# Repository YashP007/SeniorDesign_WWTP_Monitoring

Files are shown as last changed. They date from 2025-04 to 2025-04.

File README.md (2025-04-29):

# Advancing Wastewater Monitoring through Engineered Biological Sensors

**Yash Patel, Kara Walp**  
Department of Biomedical Engineering, Senior Design, Group 4 (2024–2025)  
Advisors: Rabia Tuğçe Yazicigil Kirby (BME, ECE), Miguel Jimenez (BME, MSE)

---

## Abstract
Effective industrial wastewater monitoring is critical for regulatory compliance and process optimization. However, traditional analytical techniques such as high-performance liquid chromatography (HPLC) are costly, require centralized facilities, and introduce significant latency between sampling and actionable results. Advances in synthetic biology have enabled the engineering of microbial whole-cell biosensors capable of detecting environmental contaminants with high specificity and rapid response times. Yet, practical deployment is limited by microbial instability in harsh environments and the lack of compact, low-power systems for low-signal optical outputs.

This work presents a deployable biosensing platform integrating a microbe housing and a low-power optical detection system designed for in situ wastewater monitoring. A membrane-based chamber enhances microbial viability by modulating nutrient and oxygen diffusion while preventing environmental microbial egress. Optical detection of luminescence was achieved using an analog front end with noise shaping and oversampling, enabling quantification of multiple biosensor outputs.

Experimental validation demonstrated improved microbial stability with Escherichia coli, extending viability beyond typical single-use constraints. The integrated system successfully captured optical responses from biosensors at environmentally relevant analyte concentrations. These findings highlight a promising pathway toward continuous, real-time wastewater monitoring using whole-cell biosensors. Future work must address challenges related to thermal robustness and variable contaminant backgrounds to achieve broader commercial deployment.

Contents:
Aim 1 - Creating a Microbe Housing for Deployment in Wastewater Treatment Plants
Aim 2 - Creating a Deployable Optical Detection Circuit

1. STL Files for Microbe Housing
2. Image Procesing Code for evaluating the microbe housing using the plate reader
3. KiCAD Files for Final Optical Sensing Circuit
4. Optical Sensing Circuit ESP32-C3 Microcontroller Program

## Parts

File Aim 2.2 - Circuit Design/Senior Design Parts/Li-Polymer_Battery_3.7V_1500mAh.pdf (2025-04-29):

# Li-Polymer Battery 3.7V 1500mAh (https://www.mikroe.com/li-polymer-battery-37v-1500mah)

PID: MIKROE-4473

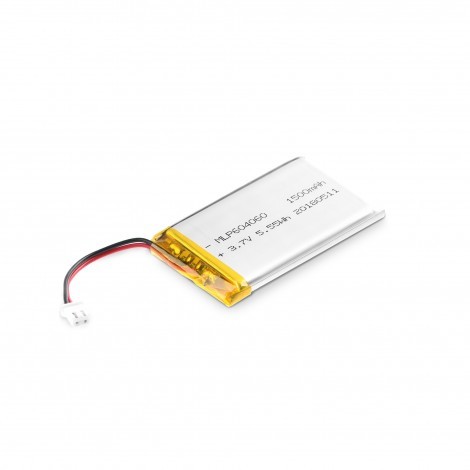
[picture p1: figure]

If you need a battery power supply, we have a great and compact solution. This rechargeable 1500mAh 3.7V battery can deliver even more.

### Downloads

MLP604060 datasheet (https://download.mikroe.com/documents/datasheets/MLP604060%201500mAh%203.7V.pdf)

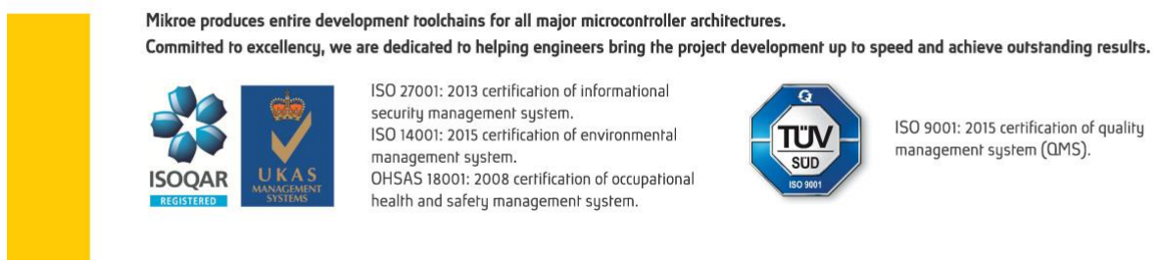
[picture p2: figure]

Powered by TCPDF (www.tcpdf.org)

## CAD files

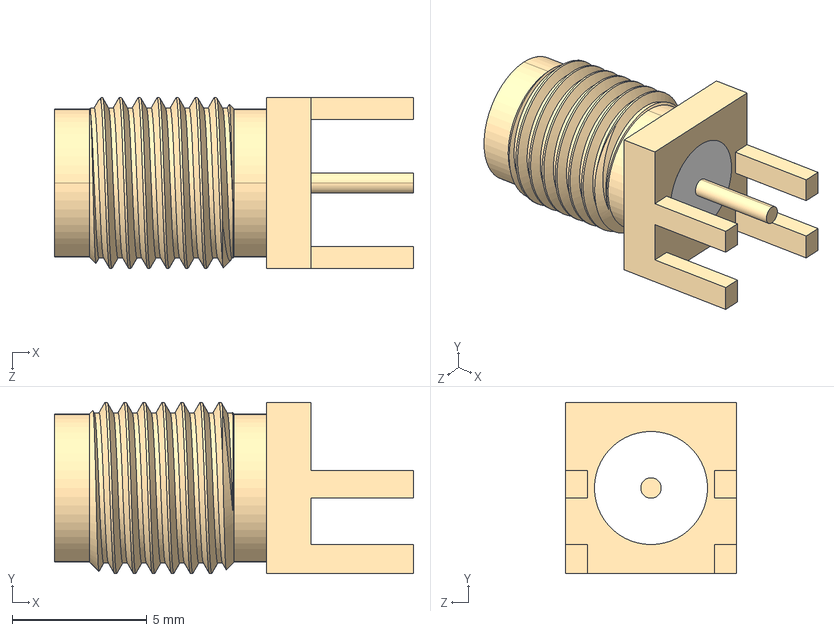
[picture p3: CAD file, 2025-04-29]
Aim 2.2 - Circuit Design/Senior Design Parts/CON_SMA_EDGE_S/CON-SMA-EDGE-S.step
13.3 x 6.35 x 6.35 mm

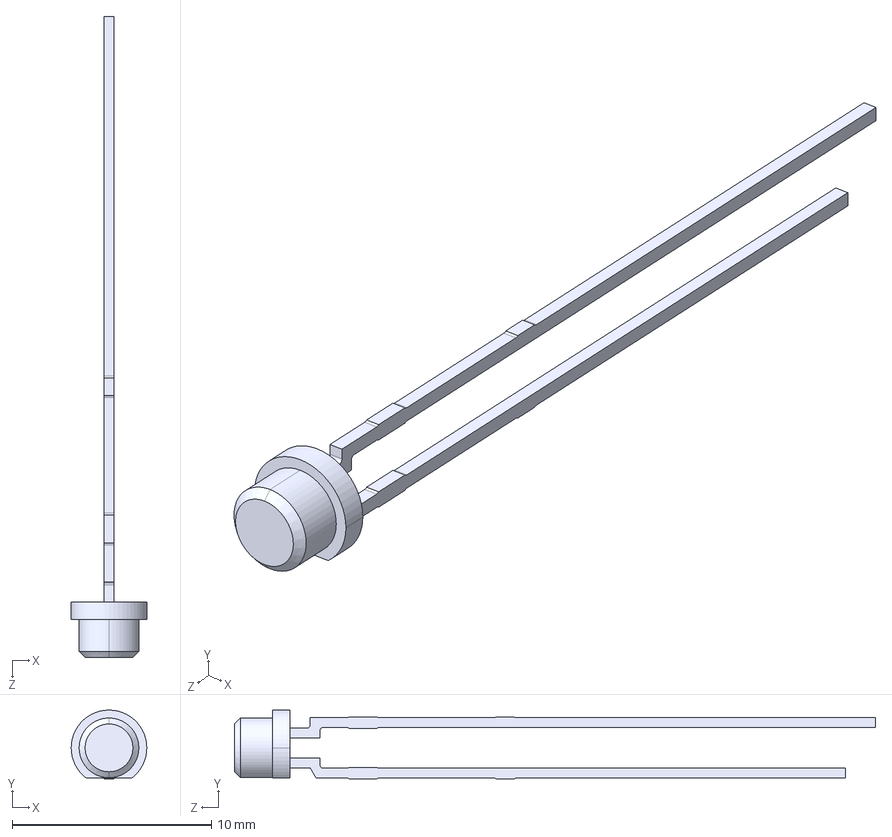
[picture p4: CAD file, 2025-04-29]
Aim 2.2 - Circuit Design/Senior Design Parts/LIB_SFH_3310/SFH_3310/3D/SFH_3310.stp
3.80 x 3.46 x 32.2 mm

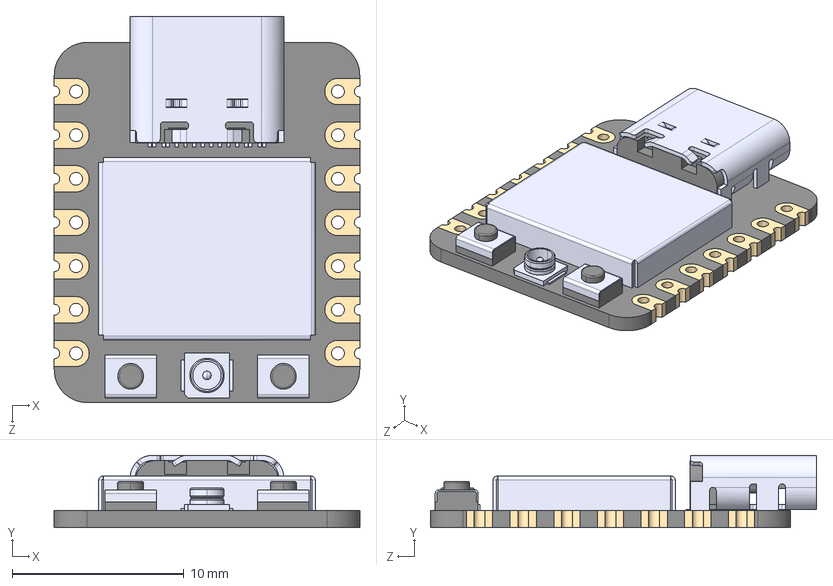
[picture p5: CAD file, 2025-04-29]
Aim 2.2 - Circuit Design/Senior Design Parts/ESP32_113991054/113991054.step
17.8 x 4.21 x 22.5 mm

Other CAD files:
Aim 2.2 - Circuit Design/Senior Design Parts/LIB_SFH_3310/SFH_3310/Allegro/sfh3310.psm
Aim 2.2 - Circuit Design/Senior Design Parts/LIB_SFH_3310/SFH_3310/DEHDL/sfh_3310/chips/chips.prt

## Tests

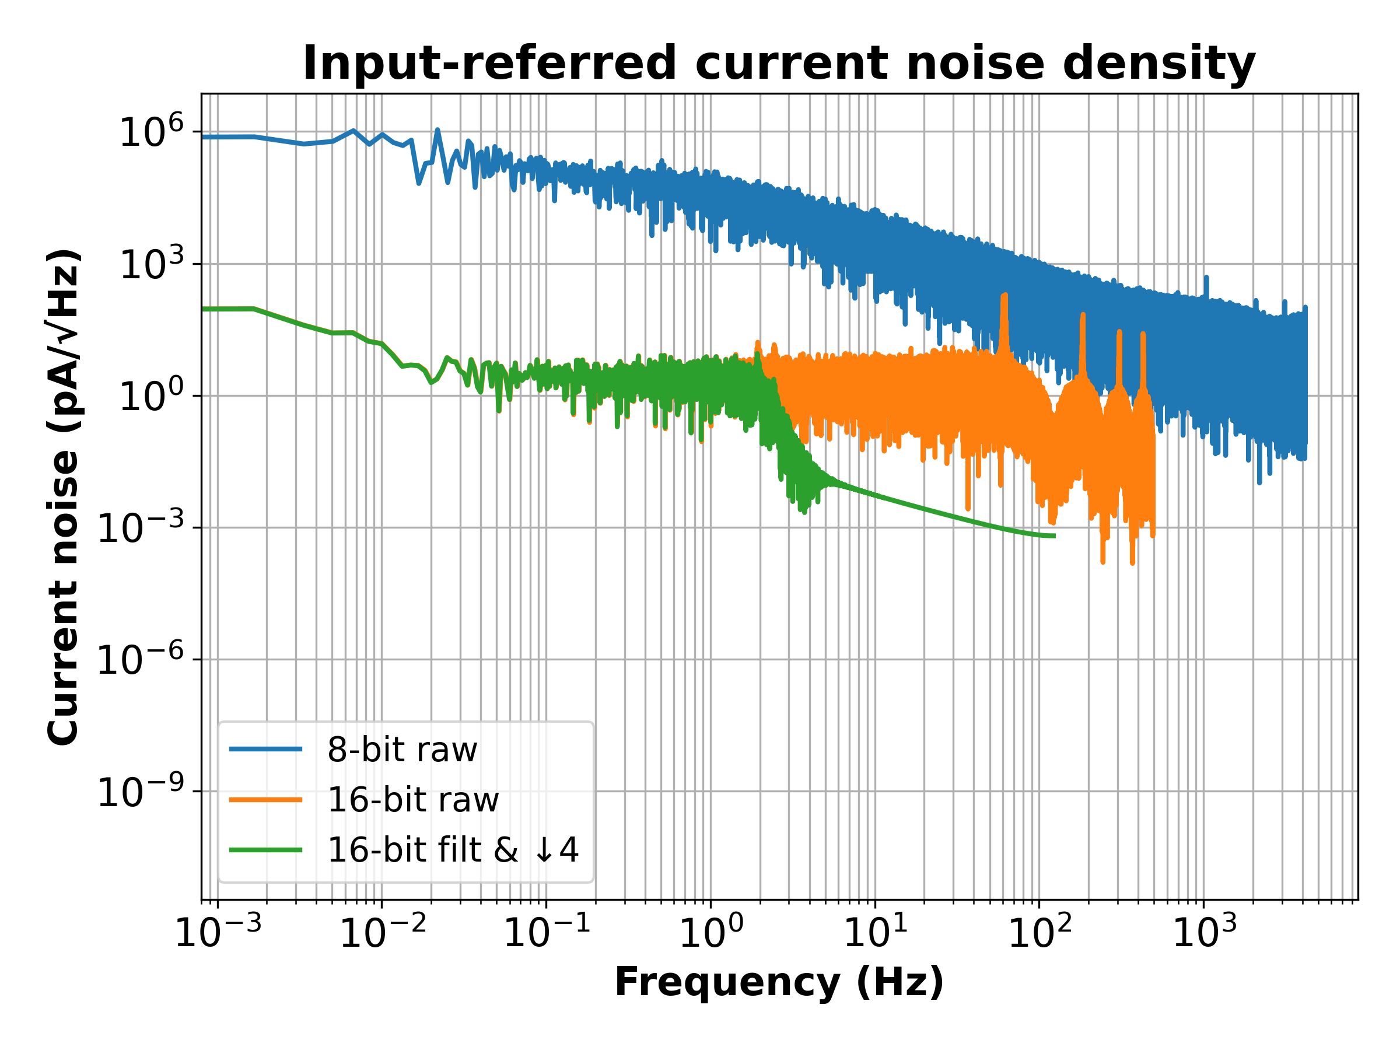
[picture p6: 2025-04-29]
Aim 2.5 - Electrical PCB Testing/Python Scripts/input_referred_current_noise.png

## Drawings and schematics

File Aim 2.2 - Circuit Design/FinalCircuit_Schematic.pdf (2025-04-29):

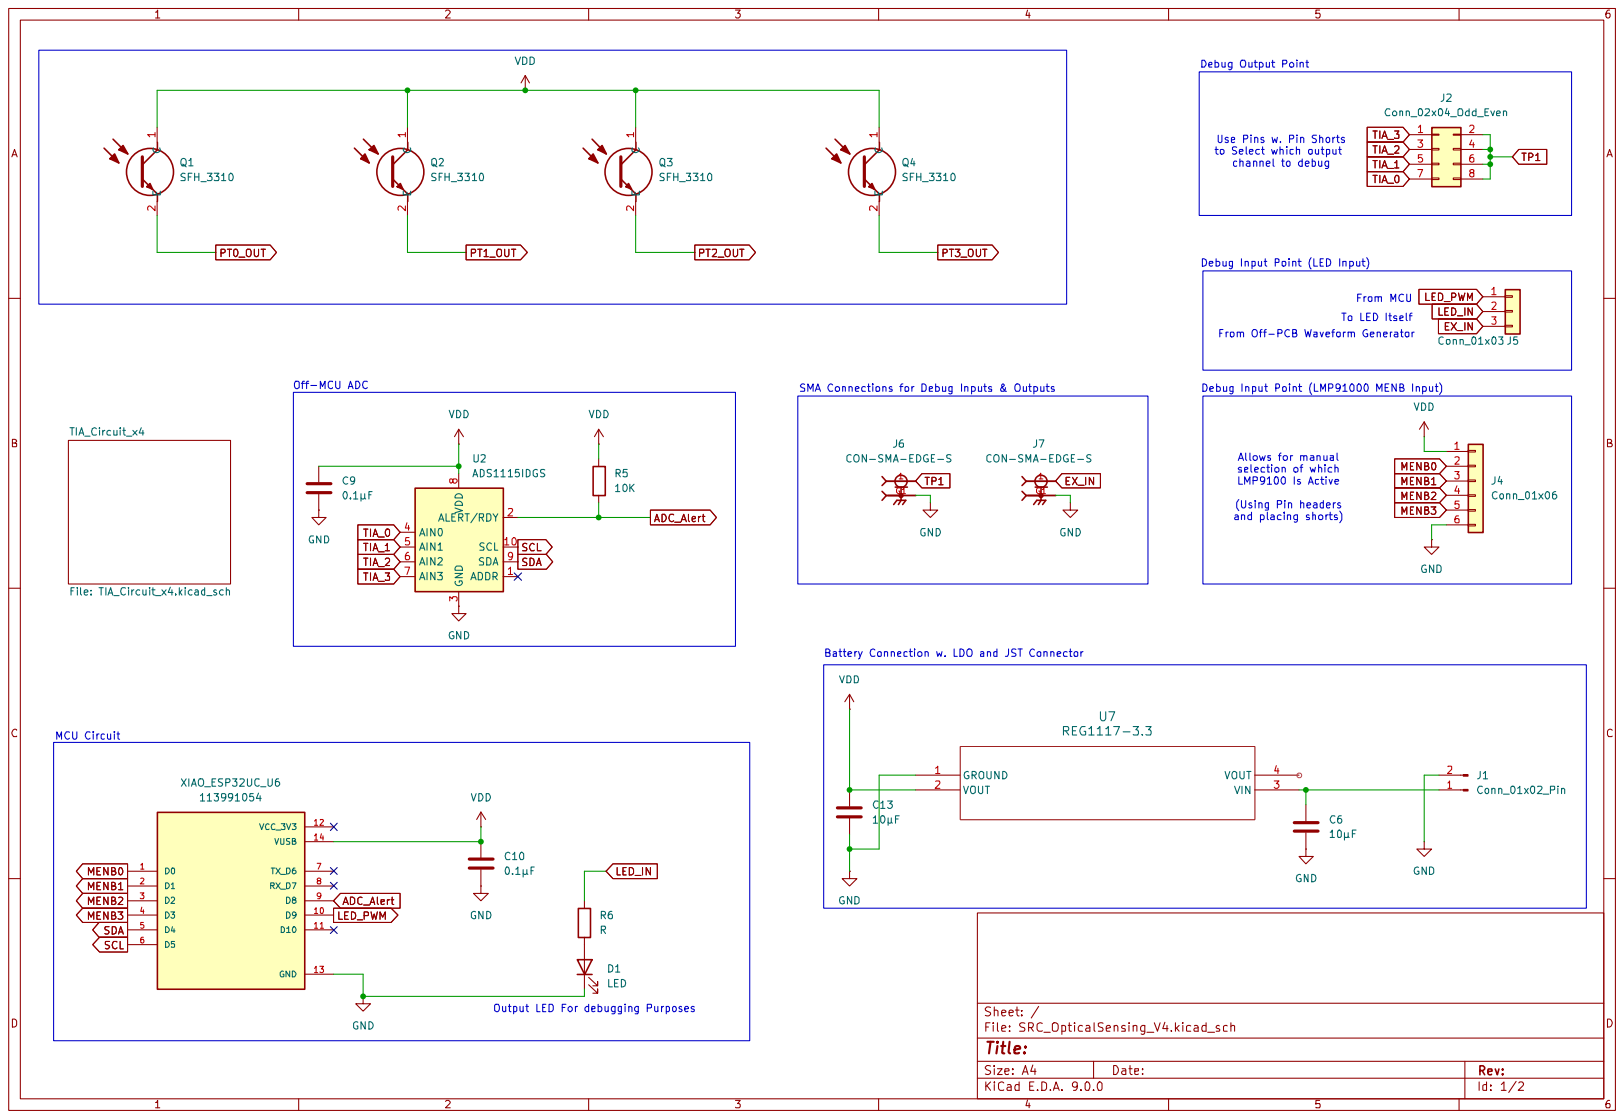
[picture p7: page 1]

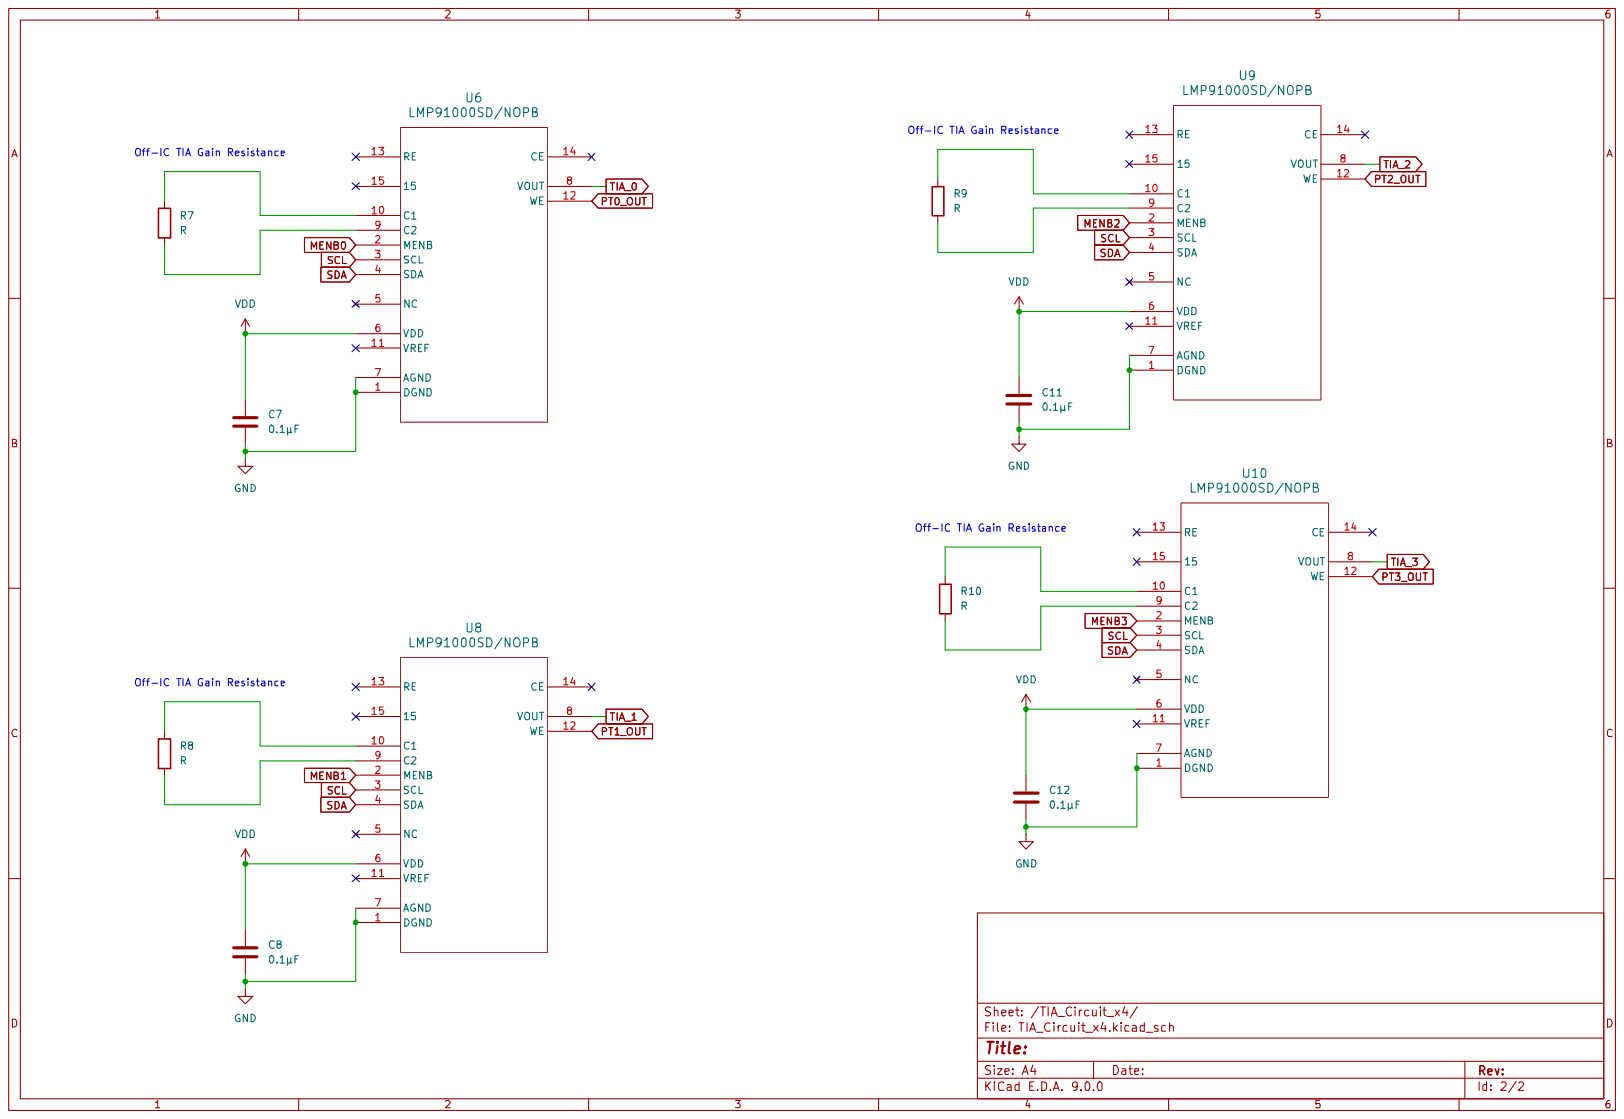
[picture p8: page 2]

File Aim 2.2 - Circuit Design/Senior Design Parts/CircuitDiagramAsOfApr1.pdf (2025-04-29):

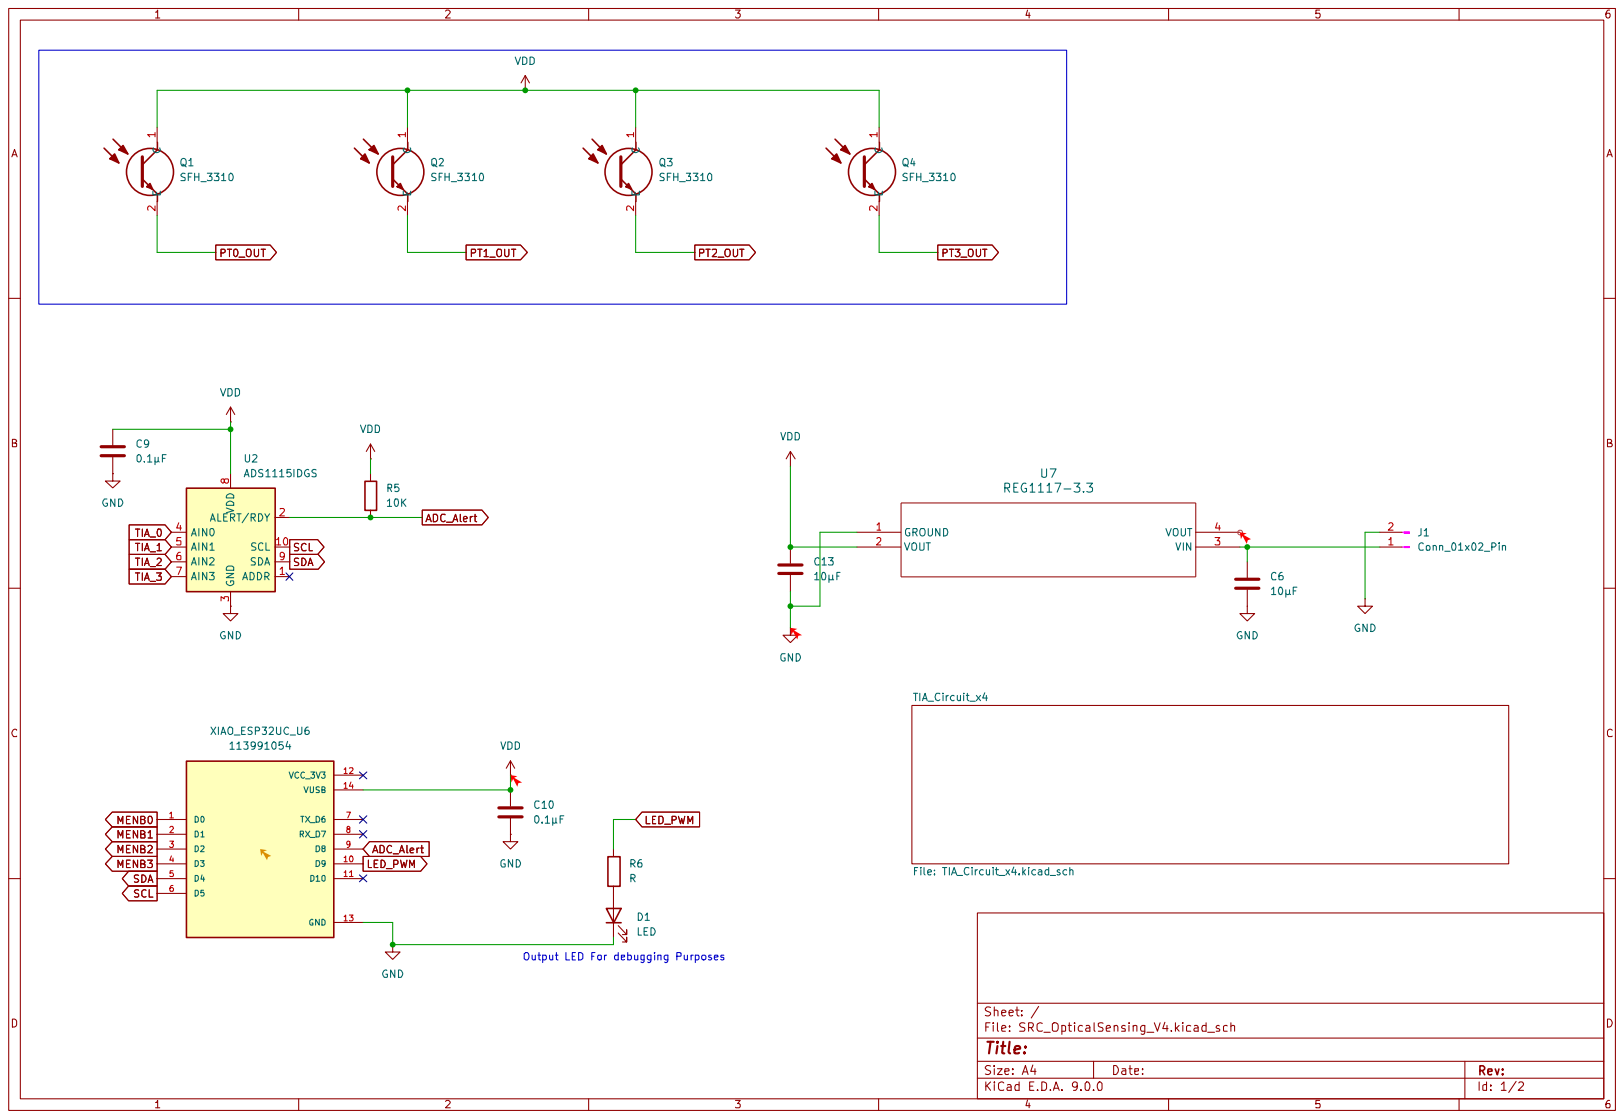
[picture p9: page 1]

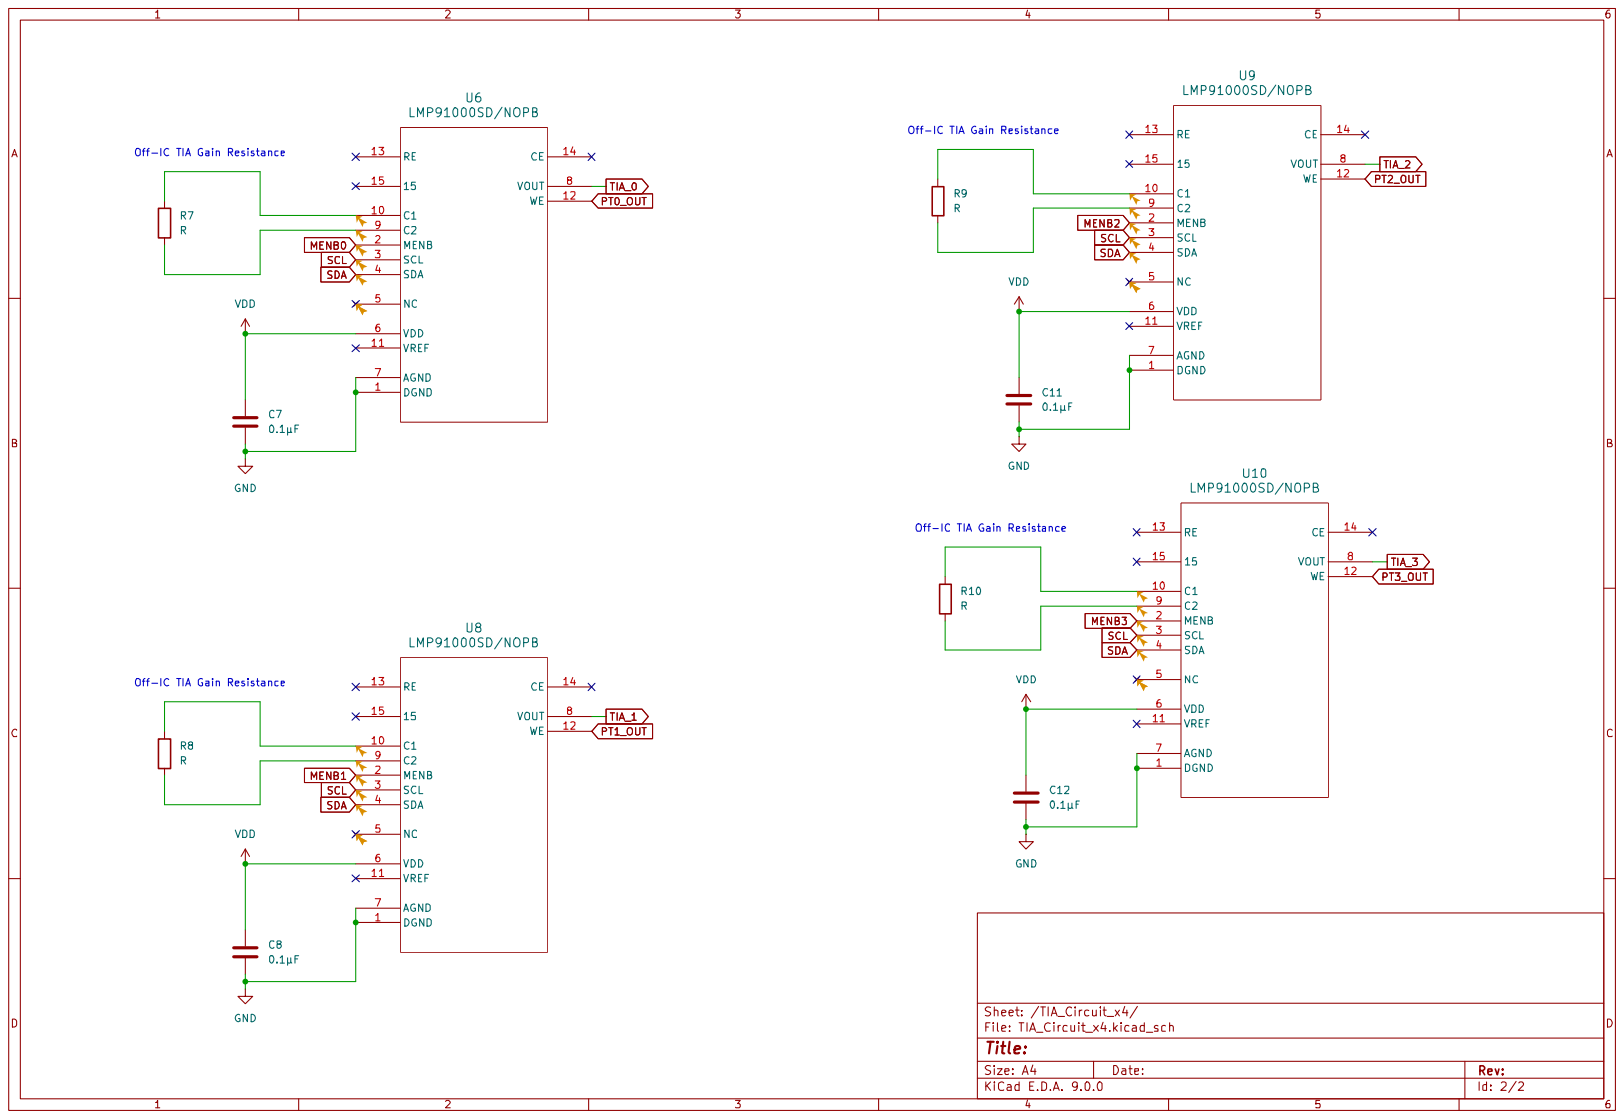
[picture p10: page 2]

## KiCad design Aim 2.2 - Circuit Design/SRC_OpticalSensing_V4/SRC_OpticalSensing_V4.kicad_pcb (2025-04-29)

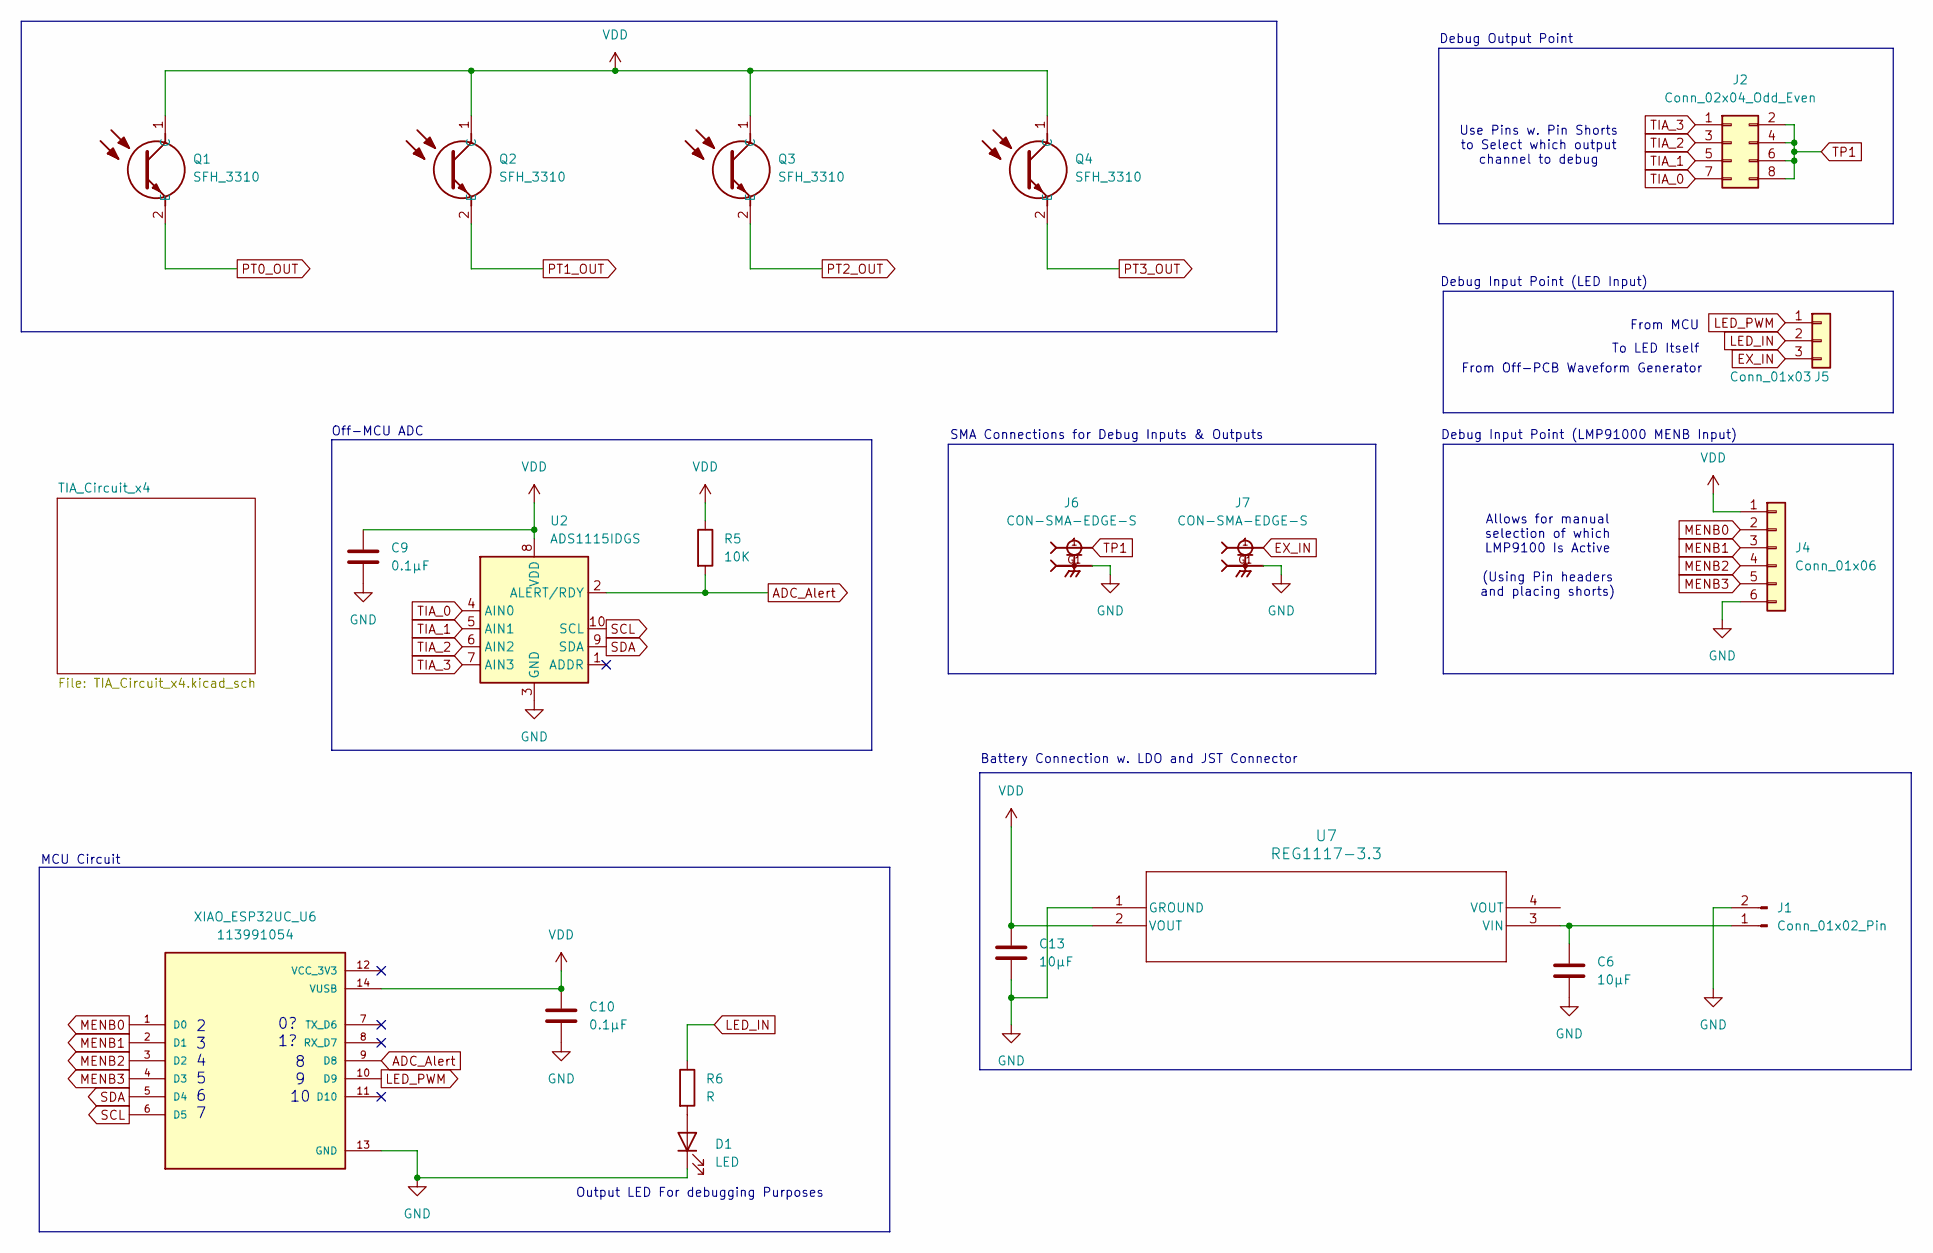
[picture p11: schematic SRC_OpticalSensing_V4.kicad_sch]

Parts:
C6, C13: 10µF; C_0805_2012Metric_Pad1.18x1.45mm_HandSolder
C9, C10: 0.1µF; C_0805_2012Metric_Pad1.18x1.45mm_HandSolder
D1: LED; LED_D5.0mm
J1: Conn_01x02_Pin; JWT_A3963_1x02_P3.96mm_Vertical
J2: Conn_02x04_Odd_Even; PinHeader_2x04_P2.54mm_Vertical
J4: Conn_01x06; PinHeader_1x06_P2.54mm_Vertical
J5: Conn_01x03; PinHeader_1x03_P2.54mm_Vertical
J6, J7: CON-SMA-EDGE-S; RFSOLUTIONS_CON-SMA-EDGE-S; PARTREV 1
Q1, Q2, Q3, Q4: SFH_3310; SFH3310; Mouser Part Number 720-SFH3310
R5: 10K; R_0805_2012Metric_Pad1.20x1.40mm_HandSolder
R6: R; R_0805_2012Metric_Pad1.20x1.40mm_HandSolder
U2: ADS1115IDGS; TSSOP-10_3x3mm_P0.5mm
U7: REG1117-3.3; DCY4
XIAO_ESP32UC_U6: 113991054; MODULE_113991054; PARTREV 23/05/2022

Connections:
ADC_Alert: R5.2, U2.2 (ALERT/RDY), XIAO_ESP32UC_U6.9 (D8)
EX_IN: J5.3, J7.1
GND: C6.2, C9.2, C10.2, C13.2, D1.1 (K), J1.2, J4.6, J6.G1, J7.G1, U2.3 (GND), U7.1 (GROUND), XIAO_ESP32UC_U6.13 (GND); also elsewhere on the board
LED_IN: J5.2, R6.1
LED_PWM: J5.1, XIAO_ESP32UC_U6.10 (D9)
MENB0: J4.2, XIAO_ESP32UC_U6.1 (D0); also elsewhere on the board
MENB1: J4.3, XIAO_ESP32UC_U6.2 (D1); also elsewhere on the board
MENB2: J4.4, XIAO_ESP32UC_U6.3 (D2); also elsewhere on the board
MENB3: J4.5, XIAO_ESP32UC_U6.4 (D3); also elsewhere on the board
unnamed: D1.2 (A), R6.2
unnamed: C6.1, J1.1, U7.3 (VIN)
PT0_OUT: Q1.2 (E); also elsewhere on the board
PT1_OUT: Q2.2 (E); also elsewhere on the board
PT2_OUT: Q3.2 (E); also elsewhere on the board
PT3_OUT: Q4.2 (E); also elsewhere on the board
SCL: U2.10 (SCL), XIAO_ESP32UC_U6.6 (D5); also elsewhere on the board
SDA: U2.9 (SDA), XIAO_ESP32UC_U6.5 (D4); also elsewhere on the board
TIA_0: J2.7, U2.4 (AIN0); also elsewhere on the board
TIA_1: J2.5, U2.5 (AIN1); also elsewhere on the board
TIA_2: J2.3, U2.6 (AIN2); also elsewhere on the board
TIA_3: J2.1, U2.7 (AIN3); also elsewhere on the board
TP1: J2.2, J2.4, J2.6, J2.8, J6.1
VDD: C9.1, C10.1, C13.1, J4.1, Q1.1 (C), Q2.1 (C), Q3.1 (C), Q4.1 (C), R5.1, U2.8 (VDD), U7.2 (VOUT), XIAO_ESP32UC_U6.14 (VUSB); also elsewhere on the board

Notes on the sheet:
Battery Connection w. LDO and JST Connector
6 7
Off-MCU ADC
From MCU
Use Pins w. Pin Shorts to Select which output channel to debug
Debug Input Point (LMP91000 MENB Input)
Allows for manual selection of which LMP9100 Is Active (Using Pin headers and placing shorts)
MCU Circuit
2 3 4 5
Debug Output Point
8 9 10
To LED Itself
SMA Connections for Debug Inputs & Outputs
0? 1?
Debug Input Point (LED Input)
From Off-PCB Waveform Generator
Output LED For debugging Purposes

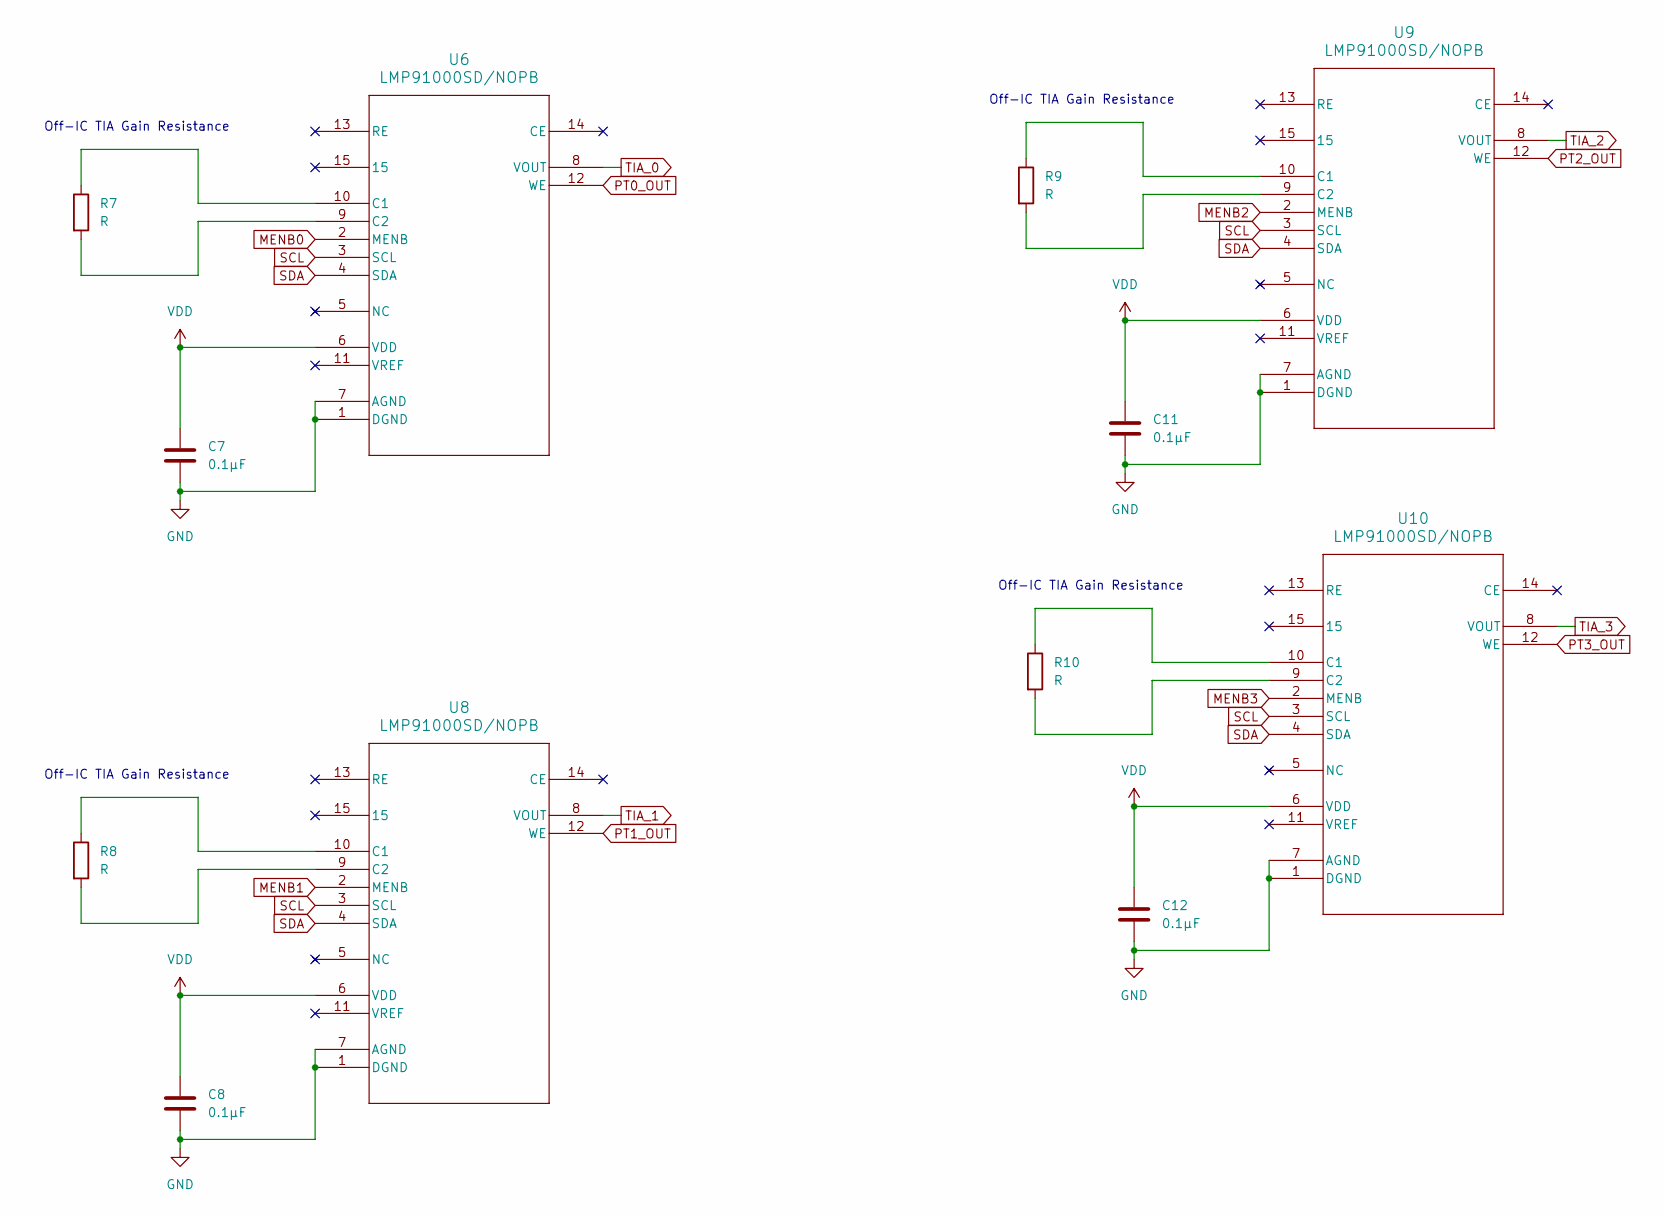
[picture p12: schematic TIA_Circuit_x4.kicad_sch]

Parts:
C7, C8, C11, C12: 0.1µF; C_0805_2012Metric_Pad1.18x1.45mm_HandSolder
R7, R8, R9, R10: R; R_0805_2012Metric_Pad1.20x1.40mm_HandSolder
U6, U8, U9, U10: LMP91000SD/NOPB; SDA14B

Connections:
GND: C7.2, C8.2, C11.2, C12.2, U6.1 (DGND), U6.7 (AGND), U8.1 (DGND), U8.7 (AGND), U9.1 (DGND), U9.7 (AGND), U10.1 (DGND), U10.7 (AGND); also elsewhere on the board
MENB0: U6.2 (MENB); also elsewhere on the board
MENB1: U8.2 (MENB); also elsewhere on the board
MENB2: U9.2 (MENB); also elsewhere on the board
MENB3: U10.2 (MENB); also elsewhere on the board
unnamed: R7.1, U6.10 (C1)
unnamed: R7.2, U6.9 (C2)
unnamed: R8.1, U8.10 (C1)
unnamed: R8.2, U8.9 (C2)
unnamed: R9.1, U9.10 (C1)
unnamed: R9.2, U9.9 (C2)
unnamed: R10.1, U10.10 (C1)
unnamed: R10.2, U10.9 (C2)
PT0_OUT: U6.12 (WE); also elsewhere on the board
PT1_OUT: U8.12 (WE); also elsewhere on the board
PT2_OUT: U9.12 (WE); also elsewhere on the board
PT3_OUT: U10.12 (WE); also elsewhere on the board
SCL: U6.3 (SCL), U8.3 (SCL), U9.3 (SCL), U10.3 (SCL); also elsewhere on the board
SDA: U6.4 (SDA), U8.4 (SDA), U9.4 (SDA), U10.4 (SDA); also elsewhere on the board
TIA_0: U6.8 (VOUT); also elsewhere on the board
TIA_1: U8.8 (VOUT); also elsewhere on the board
TIA_2: U9.8 (VOUT); also elsewhere on the board
TIA_3: U10.8 (VOUT); also elsewhere on the board
VDD: C7.1, C8.1, C11.1, C12.1, U6.6 (VDD), U8.6 (VDD), U9.6 (VDD), U10.6 (VDD); also elsewhere on the board

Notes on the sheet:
Off-IC TIA Gain Resistance

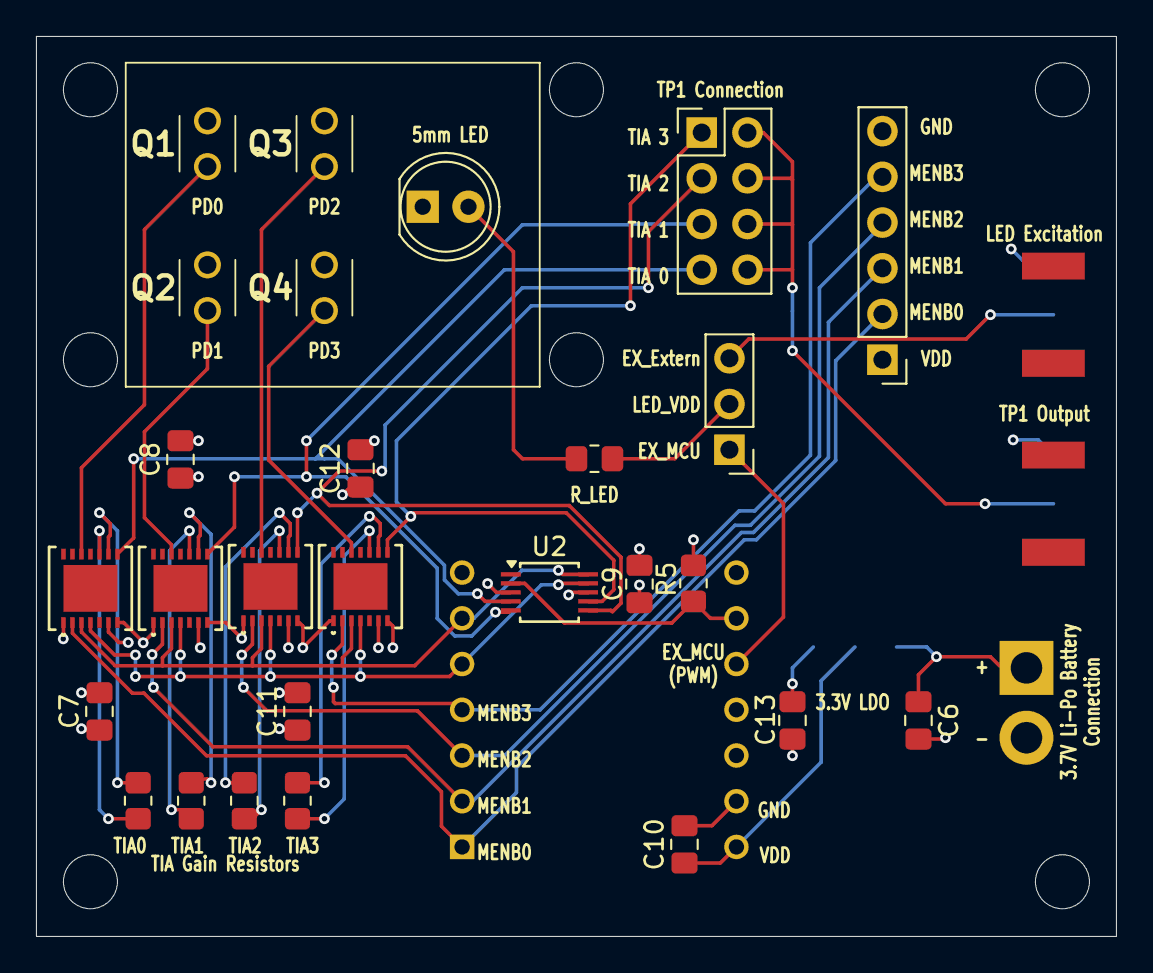
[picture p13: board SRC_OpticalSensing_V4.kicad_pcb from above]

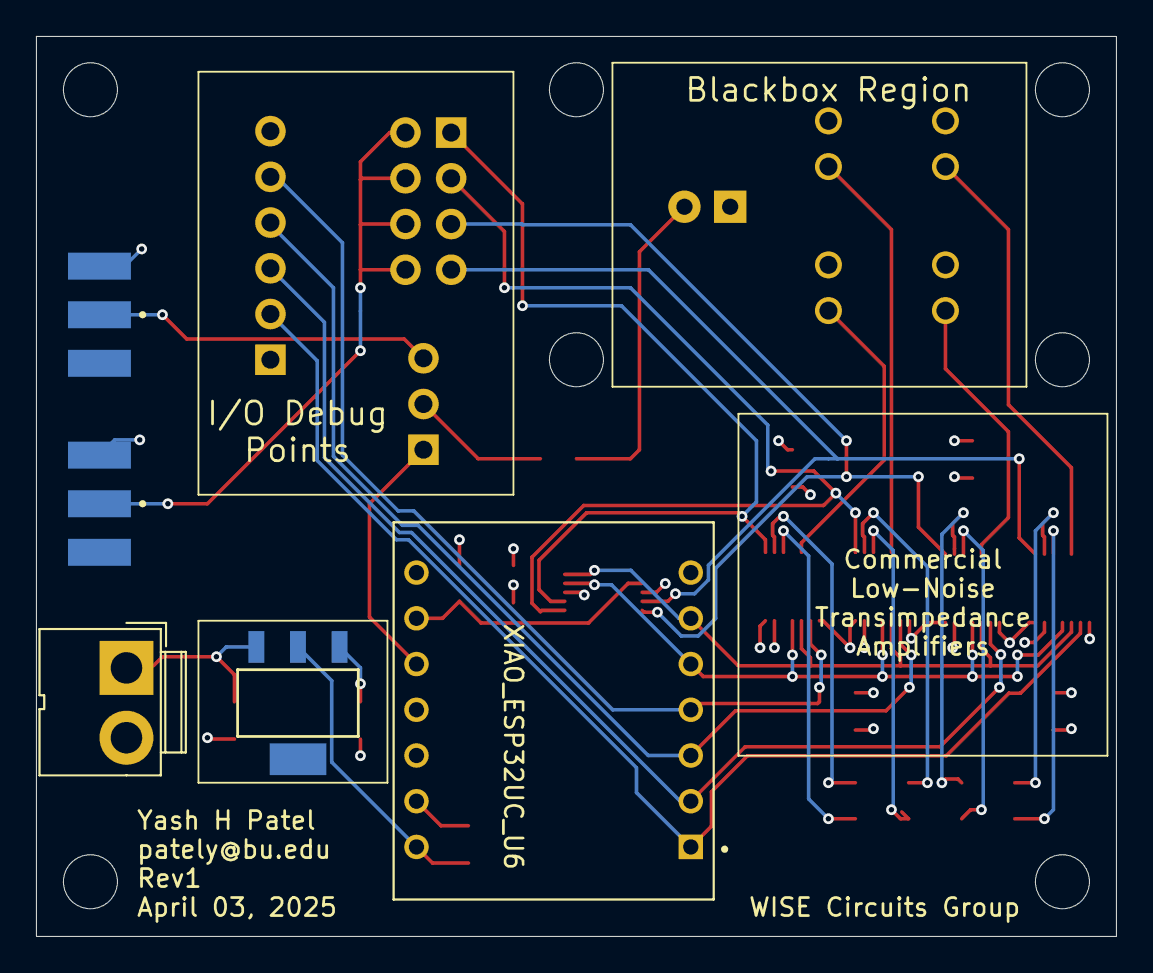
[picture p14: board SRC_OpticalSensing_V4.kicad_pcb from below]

Board: 4 copper layers, 60.0 x 50.0 mm, 32 parts (5 on the bottom side), 31 nets.

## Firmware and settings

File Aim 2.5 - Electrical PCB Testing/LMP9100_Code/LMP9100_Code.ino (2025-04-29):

#include <Wire.h>

// I²C on custom pins  
static const uint8_t SDA_PIN   = 6;  
static const uint8_t SCL_PIN   = 7;  

// MENB pins for 4 x LMP91000  
static const uint8_t menbPins[4] = { 2, 3, 4, 5 };  

// on-board LED  
static const uint8_t LED_PIN    = 9;  

// LMP91000 I²C address (7-bit)  
static const uint8_t LMP_ADDR   = 0x48;  

// Registers  
static const uint8_t REG_LOCK   = 0x01;  
static const uint8_t REG_TIACN  = 0x10;  
static const uint8_t REG_REFCN  = 0x11;  
static const uint8_t REG_MODECN = 0x12;  

// Common configuration values  
// TIACN: external Rtia, Rload=10Ω  
static const uint8_t TIACN_CFG = (0b000 << 5) | (0b00 << 0);  
// REFCN: internal ref, 50% divider, zero bias  
static const uint8_t REFCN_CFG = (0 << 7) | (0b01 << 5) | (0 << 4) | (0b0000 << 0);  
// MODECN: 3-lead amperometric  
static const uint8_t MODECN_CFG = (0 << 7) | (0b011 << 0);  

// helper to write one byte into a register  
void write8(uint8_t reg, uint8_t val) {  
  Wire.beginTransmission(LMP_ADDR);  
  Wire.write(reg);  
  Wire.write(val);  
  Wire.endTransmission();  
}  

// disable all sensors by pulling MENB high  
void disableAll() {  
  for (int i = 0; i < 4; i++) digitalWrite(menbPins[i], HIGH);  
}  

// enable exactly one sensor, leave others disabled  
void enableOne(int idx) {  
  disableAll();  
  digitalWrite(menbPins[idx], LOW);  
  delayMicroseconds(10);    // allow MENB settle  
}  

// configure a single sensor (assumes it's already enabled)  
void configOne() {  
  // unlock TIACN & REFCN  
  write8(REG_LOCK, 0x00);  
  // set TIA & load  
  write8(REG_TIACN, TIACN_CFG);  
  // set internal reference divider & bias  
  write8(REG_REFCN, REFCN_CFG);  
  // set operating mode  
  write8(REG_MODECN, MODECN_CFG);  
}  

void setup() {  
  Serial.begin(115200);  
  while(!Serial);  

  // LED  
  pinMode(LED_PIN, OUTPUT);  
  digitalWrite(LED_PIN, LOW);  

  // MENB pins  
  for (int i = 0; i < 4; i++) {  
    pinMode(menbPins[i], OUTPUT);  
    digitalWrite(menbPins[i], HIGH);  // start disabled  
  }  

  // init I²C  
  Wire.begin(SDA_PIN, SCL_PIN);  
  Wire.setClock(100000);  

  Serial.println(F("LMP91000 x4 TIA scan"));  

  // configure all devices in turn  
  for (int i = 0; i < 4; i++) {  
    enableOne(i);  
    configOne();  
    digitalWrite(LED_PIN, HIGH);  
    delay(20);  
    digitalWrite(LED_PIN, LOW);  
  }  
  disableAll();  
  Serial.println(F("All sensors configured."));  
}  

void loop() {  
  // read each sensor’s output  
  for (int i = 0; i < 4; i++) {  
    enableOne(i);  
    // small pause to let TIA output settle  
    delay(5);  

    int raw = analogRead(A0);               // 0–1023 at 5V ref  
    float volts = raw * (5.0 / 1023.0);      // convert to V  
    Serial.print("Sensor ");  
    Serial.print(i);  
    Serial.print(": ");  
    Serial.print(volts, 3);  
    Serial.print(" V");  
    if (i < 3) Serial.print(" \t");  
  }  
  disableAll();  

  // blink LED to show end of cycle  
  digitalWrite(LED_PIN, HIGH);  
  delay(50);  
  digitalWrite(LED_PIN, LOW);  

  Serial.println();  
  delay(500);  
}  

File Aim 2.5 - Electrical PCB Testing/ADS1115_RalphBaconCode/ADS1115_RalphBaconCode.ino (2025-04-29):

#include "Arduino.h"
#include "Wire.h"
#define I2Caddress 0x48

// Running average
unsigned int readings[20] = {0};
unsigned char readCnt = 0;

void setup()
{
	Serial.begin(9600);

	// Join the I2C bus as a master (call this only once)
	Wire.begin(6, 7);

	Serial.println("Setup completed.");
}

void loop()
{
	// Step 1: Point to Config register - set to continuous conversion
	Wire.beginTransmission(I2Caddress);

	// Point to Config Register
	Wire.write(0b00000001);

	// Write the MSB + LSB of Config Register
	// MSB: Bits 15:8
	// Bit  15		0=No effect, 1=Begin Single Conversion (in power down mode)
	// Bits 14:12 	How to configure A0 to A3 (comparator or single ended)
	// Bits	11:9 	Programmable Gain 000=6.144v 001=4.096v 010=2.048v .... 111=0.256v
	// Bits	8 		0=Continuous conversion mode, 1=Power down single shot
	Wire.write(0b01000010);

	// LSB:	Bits 7:0
	// Bits 7:5	Data Rate (Samples per second) 000=8, 001=16, 010=32, 011=64,
	//			100=128, 101=250, 110=475, 111=860
	// Bit 	4 	Comparator Mode 0=Traditional, 1=Window
	// Bit	3 	Comparator Polarity 0=low, 1=high
	// Bit	2 	Latching 0=No, 1=Yes
	// Bits	1:0	Comparator # before Alert pin goes high
	//			00=1, 01=2, 10=4, 11=Disable this feature
	Wire.write(0b00000010);

	// Send the above bytes as an I2C WRITE to the module
	Wire.endTransmission();

	// ====================================

	// Step 2: Set the pointer to the conversion register
	Wire.beginTransmission(I2Caddress);

	//Point to Conversion register (read only , where we get our results from)
	Wire.write(0b00000000);

	// Send the above byte(s) as a WRITE
	Wire.endTransmission();

	// =======================================

	// Step 3: Request the 2 converted bytes (MSB plus LSB)
	Wire.requestFrom(I2Caddress, 2);

	// Read two bytes and convert to full 16-bit int
	uint16_t convertedValue;

	// Read the the first byte (MSB) and shift it 8 places to the left then read
	// the second byte (LSB) into the last byte of this integer
	convertedValue = (Wire.read() << 8 | Wire.read());

	// Debug the value
	//Serial.println(convertedValue >> 6 << 6);
	//Serial.println(map(convertedValue, 0, 32767, 0, 5000));
	//Serial.println(convertedValue);
	readings[readCnt] = convertedValue;
	readCnt = readCnt == 19 ? 0 : readCnt + 1;

	// Get the average
	unsigned long totalReadings = 0;
	for (unsigned char cnt = 0; cnt < 20; cnt++){
		totalReadings += readings[cnt];
	}
	Serial.print(convertedValue); Serial.print("\t"); Serial.println(totalReadings / 20);

	delay(1);
}
